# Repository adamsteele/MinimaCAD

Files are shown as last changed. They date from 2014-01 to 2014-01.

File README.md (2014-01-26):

Minima CAD
==========

Credit goes to Adrian over at http://yo4hhp.wordpress.com/ who did the original Eagle work and Ashhar Farhan over at http://www.phonestack.com/farhan/minima.html for the original Minima design.

There is a mailing list at http://www.freelists.org/archive/minima/recent for the Minima radio.

==========

What I've done is combine the two radio boards in to a single eagle brd/sch file and wrote up a BOM for DigiKey.
What I'd like to do is be able to run boards off at OSHPark, buy a bag of parts of DigiKey and have a radio.

What still needs done:

- [ ] Hole Drill Sizes. Adrian designed this for ease of home manufacture not for OSHPark so it will take some tweaks.
- [ ] Cleanup silkscreen. It's pretty clean already there's just a bit of overlap here and there.
- [ ] Cleanup part values for consistency
- [ ] Cleanup BOM. There are a few resistor/capacitor lines that could be combined.
- [ ] Verify BOM. I went through and generally picked the cheapest parts available. Many of these have fairly loose tolerances which might not work in a radio (I don't know).

==========

Quick Notes:
- These boards aren't ready yet for OSHPark so don't spend the money on it just yet.
- The BOM is reasonably complete but it is missing tuning inductors and a knob. Money could easily be saved by not buying SMA connectors and using a bit of coax. The LCD could also be bought elsewhere to save money.

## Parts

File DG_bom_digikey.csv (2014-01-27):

Total part count: |  | 33 |  |  |  | BOM Cost: | $30.93
QTY | Value | Device | Parts | Description | Digikey P/N | Price at QTY | Total $ | URL
1 |  | 78XXL | IC4 | VOLTAGE REGULATOR | MC7805CT-BPMS-ND | $0.48 | $0.48 | http://www.digikey.com/product-detail/en/MC7805CT-BP/MC7805CT-BPMS-ND/804682
1 |  | PINHD-1X4 | BAND | PIN HEADER | - | - | - | -
1 |  | SI57X | IC2 | Any Rate I2C Prorammable XO/VCXO SiliconLabs Si570 XO and Si571 VCXO | 336-2518-ND | $13.11 | $13.11 | http://www.digikey.com/product-detail/en/570CAC000141DG/336-2518-ND/3991067
4 | 0.1 | C-EU050-024X044 | C4, C6, C7, C8 | CAPACITOR, European symbol | 445-8421-ND | $0.20 | $0.80 | http://www.digikey.com/product-detail/en/FK18X7R1E104K/445-8421-ND/2815351
1 | 10k | R-EU_0204/5 | R7 | RESISTOR, European symbol | CF18JT10K0CT-ND | $0.09 | $0.09 | http://www.digikey.com/product-detail/en/CF18JT10K0/CF18JT10K0CT-ND/2022766
1 | 10k | TRIM_EU-CA6V | R1 | POTENTIOMETER | 3306F-103-ND | $0.41 | $0.41 | http://www.digikey.com/product-detail/en/3306F-1-103/3306F-103-ND/84666
1 | 10u | CPOL-EUE2.5-5 | C1 | POLARIZED CAPACITOR, European symbol | 493-12772-1-ND | $0.12 | $0.12 | http://www.digikey.com/product-detail/en/UVR1E100MDD6TP/493-12772-1-ND/4328365
1 | 12V | PINHD-1X2 | 12V | PIN HEADER | - | - | - | -
1 | 16MHz | CRYSTALHC49S | Q1 | CRYSTAL | CTX1085-ND | $0.36 | $0.36 | http://www.digikey.com/product-detail/en/ATS16B/CTX1085-ND/2640031
1 | 1k | R-EU_0204/5 | R4 | RESISTOR, European symbol | CF18JT1K00CT-ND | $0.07 | $0.07 | http://www.digikey.com/product-detail/en/CF18JT1K00/CF18JT1K00CT-ND/2022742
2 | 22p | C-EUC1206 | C2, C3 | CAPACITOR, European symbol | 1276-2820-1-ND | $0.10 | $0.20 | http://www.digikey.com/product-detail/en/CL31C220JCCNNNC/1276-2820-1-ND/3890906
1 | 33R | R-EU_0207/15 | R2 | RESISTOR, European symbol | CF14JT33R0CT-ND | $0.08 | $0.08 | http://www.digikey.com/product-detail/en/CF14JT33R0/CF14JT33R0CT-ND/1830315
2 | 4k7 | R-EU_0204/5 | R5, R6 | RESISTOR, European symbol | CF18JT4K70CT-ND | $0.09 | $0.18 | http://www.digikey.com/product-detail/en/CF18JT4K70/CF18JT4K70CT-ND/2022758
1 | 50u | CPOL-EUE2.5-5 | C5 | POLARIZED CAPACITOR, European symbol | 493-12597-1-ND | $0.15 | $0.15 | http://www.digikey.com/product-detail/en/UVK1V470MDD1TD/493-12597-1-ND/4328678
1 | 5V | PINHD-1X1 | 5V | PIN HEADER | - | - | - | -
1 | 7805 | LM1117TO252 | IC3 |  | 1016-1584-1-ND | $0.66 | $0.66 | http://www.digikey.com/product-detail/en/SP7805V2-L%2FTR/1016-1584-1-ND/2687706
1 | BFO | PINHD-1X1 | BFO | PIN HEADER | - | - | - | -
1 | CW | PINHD-1X1 | CW | PIN HEADER | - | - | - | -
1 | FN | PINHD-1X2 | FN | PIN HEADER | - | - | - | -
1 | KEY | PINHD-1X2 | KEY | PIN HEADER | - | - | - | -
1 | MEGA8-P | MEGA8-P | IC1 | MICROCONTROLLER | ATMEGA328P-PU-ND | $3.23 | $3.23 | http://www.digikey.com/product-detail/en/ATMEGA328P-PU/ATMEGA328P-PU-ND/1914589
1 | PTT | PINHD-1X2 | PTT | PIN HEADER | - | - | - | -
1 | RST | PINHD-1X2 | RST | PIN HEADER | - | - | - | -
1 | SERIAL | PINHD-1X2 | PC | PIN HEADER | - | - | - | -
1 | T/R | PINHD-1X1 | T/R | PIN HEADER | - | - | - | -
1 | TUNE | PINHD-1X3 | TUNE | PIN HEADER | - | - | - | -
1 | TUXGR_16X2_R2 | TUXGR_16X2_R2 | DIS1 | Tuxgraphics LCD display 16x2 characters reflective, without background light | 67-1781-ND | $8.38 | $8.38 | http://www.digikey.com/product-detail/en/LCM-S01602DTR%2FM/67-1781-ND/469805
1 | VFO | BU-SMA-H | X2 | FEMALE SMA CONNECTOR | CONSMA001-ND | $2.61 | $2.61 | http://www.digikey.com/product-detail/en/CONSMA001/CONSMA001-ND/1577202

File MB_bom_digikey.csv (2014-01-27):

Total part count: |  | 204 |  |  |  | BOM Cost: | $51.26
QTY | Value | Device | Parts | Description | Digikey P/N | Price at QTY | Total $ | URL
16 | 0.1 uF | C-EU050-024X044 | C9, C56, C58, C59, C60, C61, C62, C63,C64, C65, C66, C67, C70, C71, C72, C73 | CAPACITOR, European symbol | 445-8421-ND | $0.20 | $3.20 | http://www.digikey.com/product-detail/en/FK18X7R1E104K/445-8421-ND/2815351
3 | 22 pF | C-TRIMMTZ03 | C57, C68, C69 | Trimm capacitor | SG3009-ND | $1.84 | $5.52 | http://www.digikey.com/product-detail/en/GYC65000/SG3009-ND/65256
1 | 1 uF | CPOL-EUE5-4 | C50 | POLARIZED CAPACITOR, European symbol | 493-12600-1-ND | $0.15 | $0.15 | http://www.digikey.com/product-detail/en/UVK2A010MDD1TD/493-12600-1-ND/4328681
8 | 20 MHz | CRYSTALHC49S | Q1, Q2, Q3, Q4, Q5, Q6, Q7, Q9 | CRYSTAL | CTX1106-ND | $0.36 | $2.88 | http://www.digikey.com/product-detail/en/ATS20A/CTX1106-ND/2640038
3 | 1N4007 |  | D1, D2, D3 | DIODE | 1N4007-TPMSCT-ND | $0.11 | $0.33 | http://www.digikey.com/product-detail/en/1N4007-TP/1N4007-TPMSCT-ND/773694
4 | 1N4148 | DIODE-D-5 | D4, D5, D6, D7 | DIODE | 1N4148TACT-ND | $0.10 | $0.40 | http://www.digikey.com/product-detail/en/1N4148TA/1N4148TACT-ND/1532747
1 | - | PINHD-1X1 | JP27 | PIN HEADER | - | - | -
15 | - | PINHD-1X2 | JP5, JP11, JP12, JP15, JP16, JP17, JP18, JP19, JP20, JP21, JP22, JP23, JP24, JP25, JP26 | PIN HEADER | - | - | -
3 | - | PINHD-2X3 | JP1, JP3, JP4 | PIN HEADER | - | - | -
1 | 10k | R-EU_0204/5 | R14 | RESISTOR, European symbol | CF18JT10K0CT-ND | $0.09 | $0.09 | http://www.digikey.com/product-detail/en/CF18JT10K0/CF18JT10K0CT-ND/2022766
18 | 0.1 | C-EU050-024X044 | C6, C7, C8, C10, C11, C12, C13, C14, C15, C16, C19, C22, C23, C24, C39, C42, C44, C45 | CAPACITOR, European symbol | 445-8421-ND | $0.20 | $3.60 | http://www.digikey.com/product-detail/en/FK18X7R1E104K/445-8421-ND/2815351
6 | 10 | R-EU_0204/5 | R2, R7, R17, R24, R51, R55 | RESISTOR, European symbol | CF18JT10R0CT-ND | $0.07 | $0.39 | http://www.digikey.com/product-detail/en/CF18JT10R0/CF18JT10R0CT-ND/2022697
2 | 100 | R-EU_0204/5 | R18, R30 | RESISTOR, European symbol | CF18JT100RCT-ND | $0.09 | $0.18 | http://www.digikey.com/product-detail/en/CF18JT100R/CF18JT100RCT-ND/2022718
2 | 100k | R-EU_0204/5 | R35, R41 | RESISTOR, European symbol | CF18JT100KCT-ND | $0.09 | $0.18 | http://www.digikey.com/product-detail/en/CF18JT100K/CF18JT100KCT-ND/2022790
2 | 100p | C-EU050-024X044 | C17, C18 | CAPACITOR, European symbol | 478-4214-1-ND | $0.25 | $0.50 | http://www.digikey.com/product-detail/en/5MQ101KOAAM/478-4214-1-ND/1220585
5 | 100p | C-EUC1206 | C1, C2, C3, C4, C5 | CAPACITOR, European symbol | 1276-2799-1-ND | $0.12 | $0.60 | http://www.digikey.com/product-detail/en/CL31C101JCCNFNC/1276-2799-1-ND/3890885
8 | 10k | R-EU_0204/5 | R8, R22, R23, R33, R39, R42, R46, R56 | RESISTOR, European symbol | CF18JT10K0CT-ND | $0.09 | $0.72 | http://www.digikey.com/product-detail/en/CF18JT10K0/CF18JT10K0CT-ND/2022766
1 | 10k | TRIM_EU-CA6V | R26 | POTENTIOMETER | 3306F-103-ND | $0.41 | $0.41 | http://www.digikey.com/product-detail/en/3306F-1-103/3306F-103-ND/84666
3 | 10n | C-EU050-024X044 | C47, C48, C49 | CAPACITOR, European symbol | 445-8421-ND | $0.20 | $0.60 | http://www.digikey.com/product-detail/en/FK18X7R1E104K/445-8421-ND/2815351
1 | 10u | CPOL-EUE2.5-5 | C28 | POLARIZED CAPACITOR, European symbol | 493-12772-1-ND | $0.12 | $0.12 | http://www.digikey.com/product-detail/en/UVR1E100MDD6TP/493-12772-1-ND/4328365
1 | 10 | R-EU_0204/5 | R48 | RESISTOR, European symbol | CF18JT10R0CT-ND | $0.07 | $0.07 | http://www.digikey.com/product-detail/en/CF18JT10R0/CF18JT10R0CT-ND/2022697
11 | 1k | R-EU_0204/5 | R9, R10, R13, R20, R21, R36, R37, R40, R47, R60, R61 | RESISTOR, European symbol | CF18JT1K00CT-ND | $0.07 | $0.72 | http://www.digikey.com/product-detail/en/CF18JT1K00/CF18JT1K00CT-ND/2022742
3 | 1u | CPOL-EUE2.5-5 | C35, C38, C41 | POLARIZED CAPACITOR, European symbol | 493-12600-1-ND | $0.15 | $0.45 | http://www.digikey.com/product-detail/en/UVK2A010MDD1TD/493-12600-1-ND/4328681
3 | 22 | R-EU_0204/5 | R27, R28, R34 | RESISTOR, European symbol | CF18JT22R0CT-ND | $0.09 | $0.27 | http://www.digikey.com/product-detail/en/CF18JT22R0/CF18JT22R0CT-ND/2022702
7 | 220 | R-EU_0204/5 | R1, R4, R5, R12, R43, R44, R53 | RESISTOR, European symbol | CF18JT220RCT-ND | $0.09 | $0.63 | http://www.digikey.com/product-detail/en/CF18JT220R/CF18JT220RCT-ND/2022726
2 | 22 pF | C-TRIMMTZ03 | C26, C27 | Trimm capacitor | SG3009-ND | $1.84 | $3.68 | http://www.digikey.com/product-detail/en/GYC65000/SG3009-ND/65256
1 | 2K2 | R-EU_0204/5 | R50 | RESISTOR, European symbol | CF18JT2K20CT-ND | $0.09 | $0.09 | http://www.digikey.com/product-detail/en/CF18JT2K20/CF18JT2K20CT-ND/2022750
19 | 2N3904 | 2N3904 | Q8, Q10, Q11, Q12, Q13, Q14, Q15, Q16, Q20, Q22, Q23, Q24, Q25, Q26, Q27, Q28, Q29, Q30, Q39 | NPN Transistor | 2N3904-APCT-ND | $0.17 | $3.23 | http://www.digikey.com/product-detail/en/2N3904-AP/2N3904-APCT-ND/950591
1 | 2N3906 | 2N3906 | Q21 | PNP Transistor | 2N3906-APCT-ND | $0.19 | $0.19 | http://www.digikey.com/product-detail/en/2N3906-AP/2N3906-APCT-ND/950592
5 | 2k2 | R-EU_0204/5 | R3, R6, R11, R29, R45 | RESISTOR, European symbol | CF18JT2K20CT-ND | $0.09 | $0.45 | http://www.digikey.com/product-detail/en/CF18JT2K20/CF18JT2K20CT-ND/2022750
1 | 3u | L-US0207/2V | L1 | INDUCTOR, American symbol | 495-5600-1-ND | $1.33 | $1.33 | http://www.digikey.com/product-detail/en/B82131A5202M/495-5600-1-ND/4245925
2 | 470 | R-EU_0204/5 | R15, R31 | RESISTOR, European symbol | CF18JT470RCT-ND | $0.09 | $0.18 | http://www.digikey.com/product-detail/en/CF18JT470R/CF18JT470RCT-ND/2022734
1 | 470u | CPOL-EUE2.5-5 | C30 | POLARIZED CAPACITOR, European symbol | 493-12892-1-ND | $0.18 | $0.18 | http://www.digikey.com/product-detail/en/UVY1A471MED1TD/493-12892-1-ND/4328509
2 | 47k | R-EU_0204/5 | R32, R59 | RESISTOR, European symbol | CF18JT47K0CT-ND | $0.09 | $0.18 | http://www.digikey.com/product-detail/en/CF18JT47K0/CF18JT47K0CT-ND/2022782
7 | 4k7 | R-EU_0204/5 | R16, R25, R38, R49, R52, R54, R64 | RESISTOR, European symbol | CF18JT4K70CT-ND | $0.09 | $0.63 | http://www.digikey.com/product-detail/en/CF18JT4K70/CF18JT4K70CT-ND/2022758
12 | 50u | CPOL-EUE2.5-5 | C20, C21, C25, C29, C31, C32, C33, C36, C37, C40, C43, C46 | POLARIZED CAPACITOR, European symbol | 445-8425-ND | $0.22 | $2.66 | http://www.digikey.com/product-detail/en/FK18X7R1E474K/445-8425-ND/2815355
1 | 51 | R-EU_0204/5 | R19 | RESISTOR, European symbol | CF18JT51R0CT-ND | $0.09 | $0.09 | http://www.digikey.com/product-detail/en/CF18JT51R0/CF18JT51R0CT-ND/2022711
2 | 6k8 | R-EU_0204/5 | R57, R58 | RESISTOR, European symbol | CF18JT6K80CT-ND | $0.09 | $0.18 | http://www.digikey.com/product-detail/en/CF18JT6K80/CF18JT6K80CT-ND/2022762
1 | 78L05 | 78LXX | IC1 | VOLTAGE REGULATOR | 497-2952-ND | $0.39 | $0.39 | http://www.digikey.com/product-detail/en/L78L05ACZ/497-2952-ND/634716
1 | 20 MHz (BFO) | CRYSTALHC49S | Q17 | CRYSTAL | CTX1106-ND | $0.36 | $0.36 | http://www.digikey.com/product-detail/en/ATS20A/CTX1106-ND/2640038
1 | BFO | PINHD-1X1 | JP9 | PIN HEADER | - | - | -
1 | CW | PINHD-1X1 | JP10 | PIN HEADER | - | - | -
1 | 12VDC | G5V-2 | K2 | OMRON PCB Relay | Z768-ND | $2.97 | $2.97 | http://www.digikey.com/product-detail/en/G5V-2-DC12/Z768-ND/87821
3 | G5V1 | G5V1 | K1, K3, K4 | RELAY | Z774-ND | $2.05 | $6.15 | http://www.digikey.com/product-detail/en/G5V-1-DC12/Z774-ND/87833
2 | J310 | J310 | Q18, Q19 | N-Channel RF Amplifier J309, J310 | J310GOS-ND | $0.55 | $1.10 | http://www.digikey.com/product-detail/en/J310G/J310GOS-ND/918462
1 | MIC | PINHD-1X2 | JP6 | PIN HEADER | - | - | -
4 | PAD-RND3.0 | PAD-RND3.0 | H1, H2, H3, H4 | MOUNTING PAD, round | - | - | -
1 | PA | BU-SMA-V | X3 | FEMALE SMA CONNECTOR | CONSMA001-ND | $2.61 | $2.61 | http://www.digikey.com/product-detail/en/CONSMA001/CONSMA001-ND/1577202
1 | R/T | PINHD-1X1 | JP8 | PIN HEADER | - | - | -
1 | RFC | PINHD-1X2 | JP2 | PIN HEADER | - | - | -
1 | VFO | BU-SMA-V | X1 | FEMALE SMA CONNECTOR | CONSMA001-ND | $2.61 | $2.61 | http://www.digikey.com/product-detail/en/CONSMA001/CONSMA001-ND/1577202
1 | VOL | PINHD-1X3 | JP7 | PIN HEADER | - | - | -

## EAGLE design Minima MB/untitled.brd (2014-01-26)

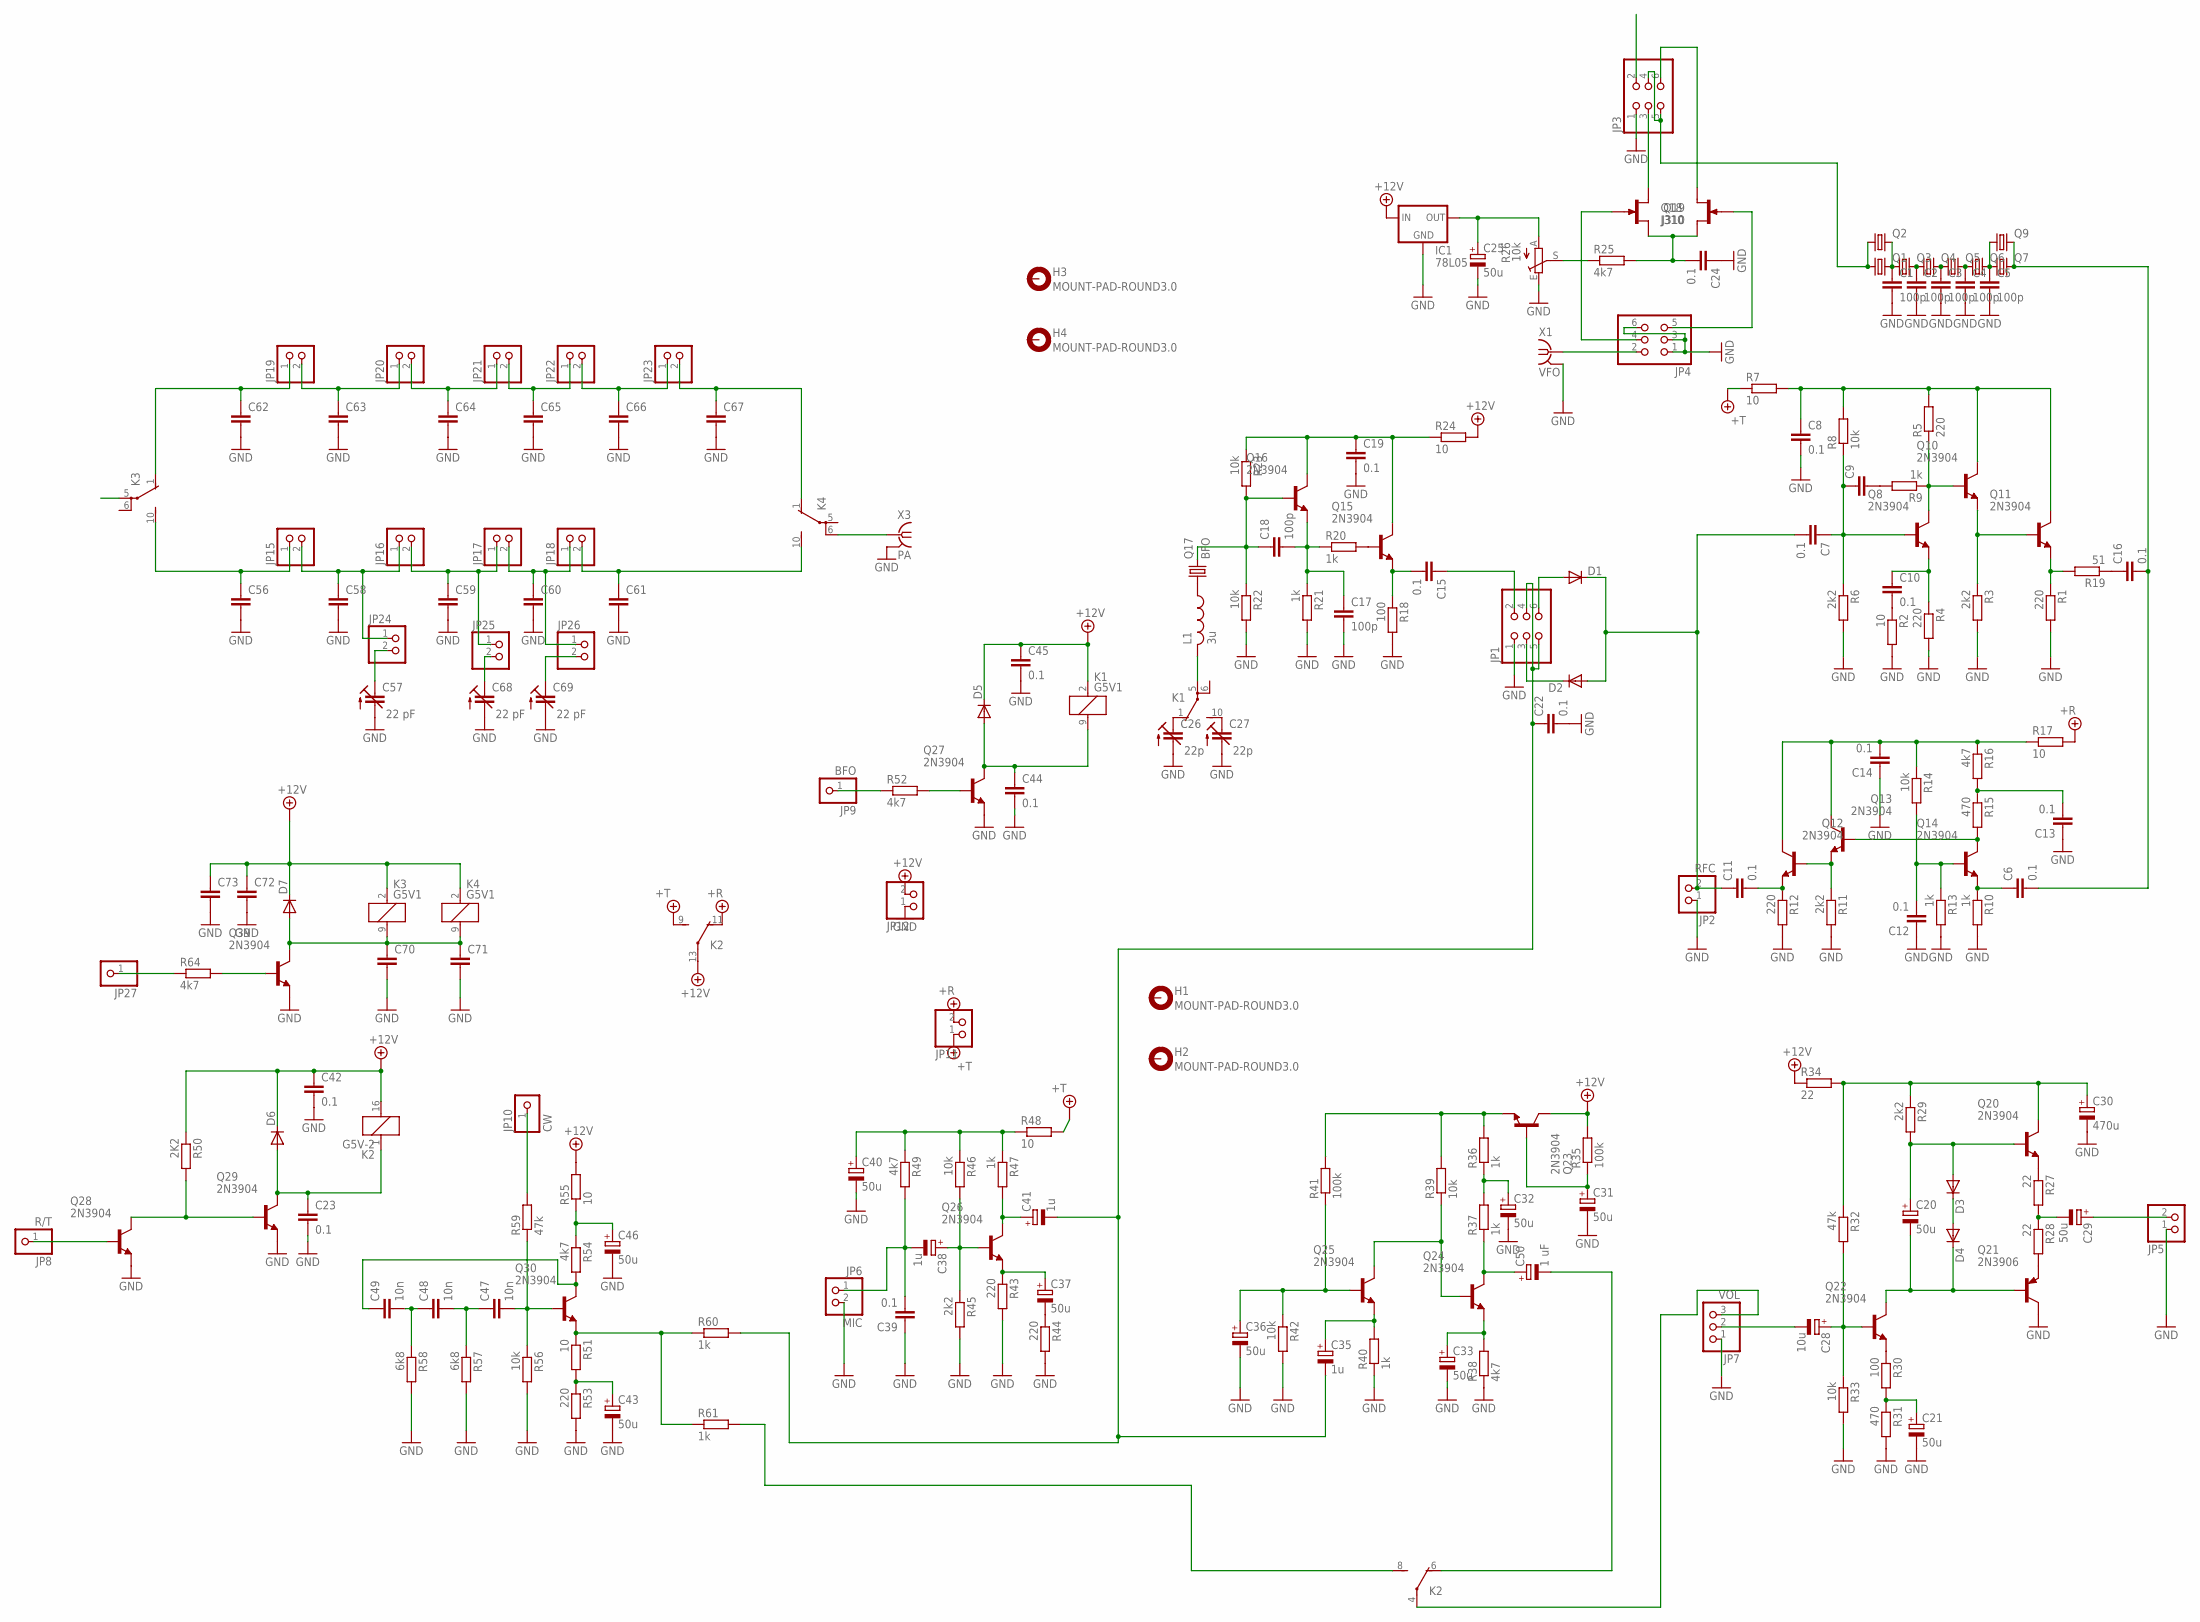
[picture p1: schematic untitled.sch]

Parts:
C1, C2, C3, C4, C5: 100p; C1206
C6, C7, C8, C10, C11, C12, C13, C14, C15, C16, C19, C22, C23, C24, C39, C42, C44, C45: 0.1; C050-024X044
C9, C56, C58, C59, C60, C61, C62, C63, C64, C65, C66, C67, C70, C71, C72, C73: C-EU050-024X044; C050-024X044
C17, C18: 100p; C050-024X044
C20, C21, C25, C29, C31, C32, C33, C36, C37, C40, C43, C46: 50u; E2,5-5
C26, C27: 22p; CTRIMTZ03
C28: 10u; E2,5-5
C30: 470u; E2,5-5
C35, C38, C41: 1u; E2,5-5
C47, C48, C49: 10n; C050-024X044
C50: 1 uF; E5-4
C57, C68, C69: 22 pF; CTRIMTZ03
D1, D2, D3, D4, D5, D6, D7: DIODE-D-5; D-5
H1, H2, H3, H4: MOUNT-PAD-ROUND3.0; 3,0-PAD
IC1: 78L05; 78LXX
JP1, JP3, JP4: PINHD-2X3; 2X03
JP2: RFC; 1X02
JP5, JP11, JP12, JP15, JP16, JP17, JP18, JP19, JP20, JP21, JP22, JP23, JP24, JP25, JP26: PINHD-1X2; 1X02
JP6: MIC; 1X02
JP7: VOL; 1X03
JP8: R/T; 1X01
JP9: BFO; 1X01
JP10: CW; 1X01
JP27: PINHD-1X1; 1X01
K1, K3, K4: G5V1
K2: G5V-2
L1: 3u; 0207/2V
Q1, Q2, Q3, Q4, Q5, Q6, Q7, Q9: CRYSTALHC49S; HC49/S
Q8, Q10, Q11, Q12, Q13, Q14, Q15, Q16, Q20, Q22, Q23, Q24, Q25, Q26, Q27, Q28, Q29, Q30, Q39: 2N3904; TO92
Q17: BFO; HC49/S
Q18, Q19: J310; TO92R
Q21: 2N3906; TO92
R1, R4, R5, R12, R43, R44, R53: 220; 0204/5
R2, R7, R17, R24, R48, R51, R55: 10; 0204/5
R3, R6, R11, R29, R45: 2k2; 0204/5
R8, R14, R22, R23, R33, R39, R42, R46, R56: 10k; 0204/5
R9, R10, R13, R20, R21, R36, R37, R40, R47, R60, R61: 1k; 0204/5
R15, R31: 470; 0204/5
R16, R25, R38, R49, R52, R54, R64: 4k7; 0204/5
R18, R30: 100; 0204/5
R19: 51; 0204/5
R26: 10k; CA6V
R27, R28, R34: 22; 0204/5
R32, R59: 47k; 0204/5
R35, R41: 100k; 0204/5
R50: 2K2; 0204/5
R57, R58: 6k8; 0204/5
X1: VFO; BU-SMA-V
X3: PA; BU-SMA-V

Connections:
+5V/1: JP11.2, K2.11 (O), R17.2
+5V/2: JP11.1, K2.9 (S), R7.1, R48.2
+12V: C42.1, C45.1, C72.1, C73.1, D5.C, D6.C, D7.C, IC1.IN, JP12.2, K1.2 (1), K2.13, K2.16 (2), K3.2 (1), K4.2 (1), Q23.1 (C), R24.2, R34.1, R35.2, R50.1, R55.2
GND: C1.2, C2.2, C3.2, C4.2, C5.2, C8.2, C12.1, C13.1, C14.1, C17.2, C19.2, C21.-, C22.2, C23.2, C24.1, C25.-, C26.2 (A), C27.2 (A), C30.-, C31.-, C32.-, C33.-, C36.-, C39.1, C40.-, C42.2, C43.-, C44.2, C45.2, C46.-, C56.2, C57.2 (A), C58.2, C59.2, C60.2, C61.2, C62.2, C63.2, C64.2, C65.2, C66.2, C67.2, C68.2 (A), C69.2 (A), C70.2, C71.2, C72.2, C73.2, IC1.GND, JP1.1, JP2.1, JP3.1, JP4.1, JP4.3, JP4.6, JP5.1, JP6.2, JP7.1, JP12.1, Q21.1 (C), Q27.3 (E), Q28.3 (E), Q29.3 (E), Q39.3 (E), R1.2, R2.2, R3.2, R4.2, R6.2, R10.2, R11.2, R12.2, R13.2, R18.2, R21.2, R22.2, R26.E, R31.2, R33.2, R38.1, R40.1, R42.2, R43.2, R44.2, R45.2, R53.2, R56.2, R57.2, R58.2, X1.2 (GND), X1.3 (GND), X1.4 (GND), X1.5 (GND), X3.2 (GND), X3.3 (GND), X3.4 (GND), X3.5 (GND)
unnamed: C1.1, Q1.2, Q2.2, Q3.1
unnamed: C2.1, Q3.2, Q4.1
unnamed: C3.1, Q4.2, Q5.1
unnamed: C4.1, Q5.2, Q6.1
unnamed: C5.1, Q6.2, Q7.1, Q9.1
unnamed: C6.2, C16.2, Q7.2, Q9.2
unnamed: C26.1 (E), K1.1 (O)
unnamed: C10.1, Q8.3 (E), R4.1
unnamed: C10.2, R2.1
unnamed: C7.1, C9.1, Q8.2 (B), R6.1, R8.1
unnamed: Q8.1 (C), Q10.2 (B), R5.1, R9.1
unnamed: Q10.3 (E), Q11.2 (B), R3.1
unnamed: Q11.3 (E), R1.1, R19.2
unnamed: C8.1, Q10.1 (C), Q11.1 (C), R5.2, R7.2, R8.2
unnamed: C16.1, R19.1
unnamed: C9.2, R9.2
unnamed: Q12.2 (B), Q13.3 (E), R11.1
unnamed: C11.2, Q12.3 (E), R12.1
unnamed: C14.2, Q12.1 (C), Q13.1 (C), R14.1, R16.1, R17.1
unnamed: C27.1 (E), K1.10 (S)
unnamed: C12.2, Q14.2 (B), R13.1, R14.2
unnamed: C6.1, Q14.3 (E), R10.1
unnamed: Q13.2 (B), Q14.1 (C), R15.2
unnamed: C13.2, R15.1, R16.2
unnamed: C15.2, Q15.3 (E), R18.1
unnamed: Q15.2 (B), R20.2
unnamed: C17.1, C18.2, Q16.3 (E), R20.1, R21.1
unnamed: C19.1, Q15.1 (C), Q16.1 (C), R23.1, R24.1
unnamed: C15.1, JP1.2
unnamed: C18.1, Q16.2 (B), Q17.2, R22.1, R23.2
unnamed: L1.1, Q17.1
unnamed: K1.5, L1.2
unnamed: R25.1, R26.S
unnamed: Q20.3 (E), R27.1
unnamed: Q27.2 (B), R52.2
unnamed: D1.A, JP1.6
unnamed: D2.C, JP1.3
unnamed: C7.2, C11.1, D1.C, D2.A, JP2.2
unnamed: JP3.4, JP3.5, Q1.1, Q2.1
unnamed: JP3.3, Q18.D
unnamed: JP3.6, Q19.D
unnamed: C24.2, Q18.S, Q19.S, R25.2
unnamed: JP4.5, Q19.G
unnamed: JP4.4, Q18.G
unnamed: C29.-, R27.2, R28.1
unnamed: JP4.2, X1.1
unnamed: Q21.3 (E), R28.2
unnamed: C25.+, IC1.OUT, R26.A
unnamed: D3.C, D4.A
unnamed: C20.-, D4.C, Q21.2 (B), Q22.1 (C)
unnamed: C20.+, D3.A, Q20.2 (B), R29.2
unnamed: C30.+, Q20.1 (C), R29.1, R32.1, R34.2
unnamed: Q22.3 (E), R30.1
unnamed: C21.+, R30.2, R31.1
unnamed: C28.+, Q22.2 (B), R32.2, R33.1
unnamed: C29.+, JP5.2
unnamed: C28.-, JP7.2
unnamed: C31.+, Q23.2 (B), R35.1
unnamed: Q23.3 (E), R36.2, R39.2, R41.2
unnamed: C32.+, R36.1, R37.2
unnamed: C50.+, Q24.1 (C), R37.1
unnamed: C33.+, Q24.3 (E), R38.2
unnamed: Q24.2 (B), Q25.1 (C), R39.1
unnamed: JP9.1, R52.1
unnamed: C35.+, Q25.3 (E), R40.2
unnamed: C36.+, Q25.2 (B), R41.1, R42.1
unnamed: C37.+, Q26.3 (E), R43.1
unnamed: C37.-, R44.1
unnamed: C38.+, Q26.2 (B), R45.1, R46.2
unnamed: C41.+, Q26.1 (C), R47.2
unnamed: C40.+, R46.1, R47.1, R48.1, R49.1
unnamed: C38.-, C39.2, JP6.1, R49.2
unnamed: JP7.3, K2.4
unnamed: C22.1, C35.-, C41.-, JP1.4, JP1.5, R60.2
unnamed: C50.-, K2.6 (O)
unnamed: JP8.1, Q28.2 (B)
unnamed: C23.1, D6.A, K2.1, Q29.1 (C)
unnamed: Q28.1 (C), Q29.2 (B), R50.2
unnamed: C44.1, D5.A, K1.9 (2), Q27.1 (C)
unnamed: Q30.3 (E), R51.1, R60.1, R61.1
unnamed: C43.+, R51.2, R53.1
unnamed: C49.1, Q30.1 (C), R54.2
unnamed: C46.+, R54.1, R55.1
unnamed: C47.2, Q30.2 (B), R56.1, R59.1
unnamed: C47.1, C48.2, R57.1
unnamed: C48.1, C49.2, R58.1
unnamed: JP10.1, R59.2
unnamed: K2.8 (S), R61.2
unnamed: C56.1, JP15.1, K3.10 (S)
unnamed: C58.1, JP15.2, JP16.1, JP24.1
unnamed: C59.1, JP16.2, JP17.1, JP25.1
unnamed: C60.1, JP17.2, JP18.1, JP26.1
unnamed: C61.1, JP18.2, K4.10 (S)
unnamed: C62.1, JP19.1, K3.1 (O)
unnamed: C63.1, JP19.2, JP20.1
unnamed: C64.1, JP20.2, JP21.1
unnamed: C65.1, JP21.2, JP22.1
unnamed: C66.1, JP22.2, JP23.1
unnamed: C67.1, JP23.2, K4.1 (O)
unnamed: K4.6, X3.1
unnamed: JP3.2, K3.5
unnamed: C57.1 (E), JP24.2
unnamed: C68.1 (E), JP25.2
unnamed: C69.1 (E), JP26.2
unnamed: Q39.2 (B), R64.2
unnamed: JP27.1, R64.1
unnamed: C70.1, C71.1, D7.A, K3.9 (2), K4.9 (2), Q39.1 (C)

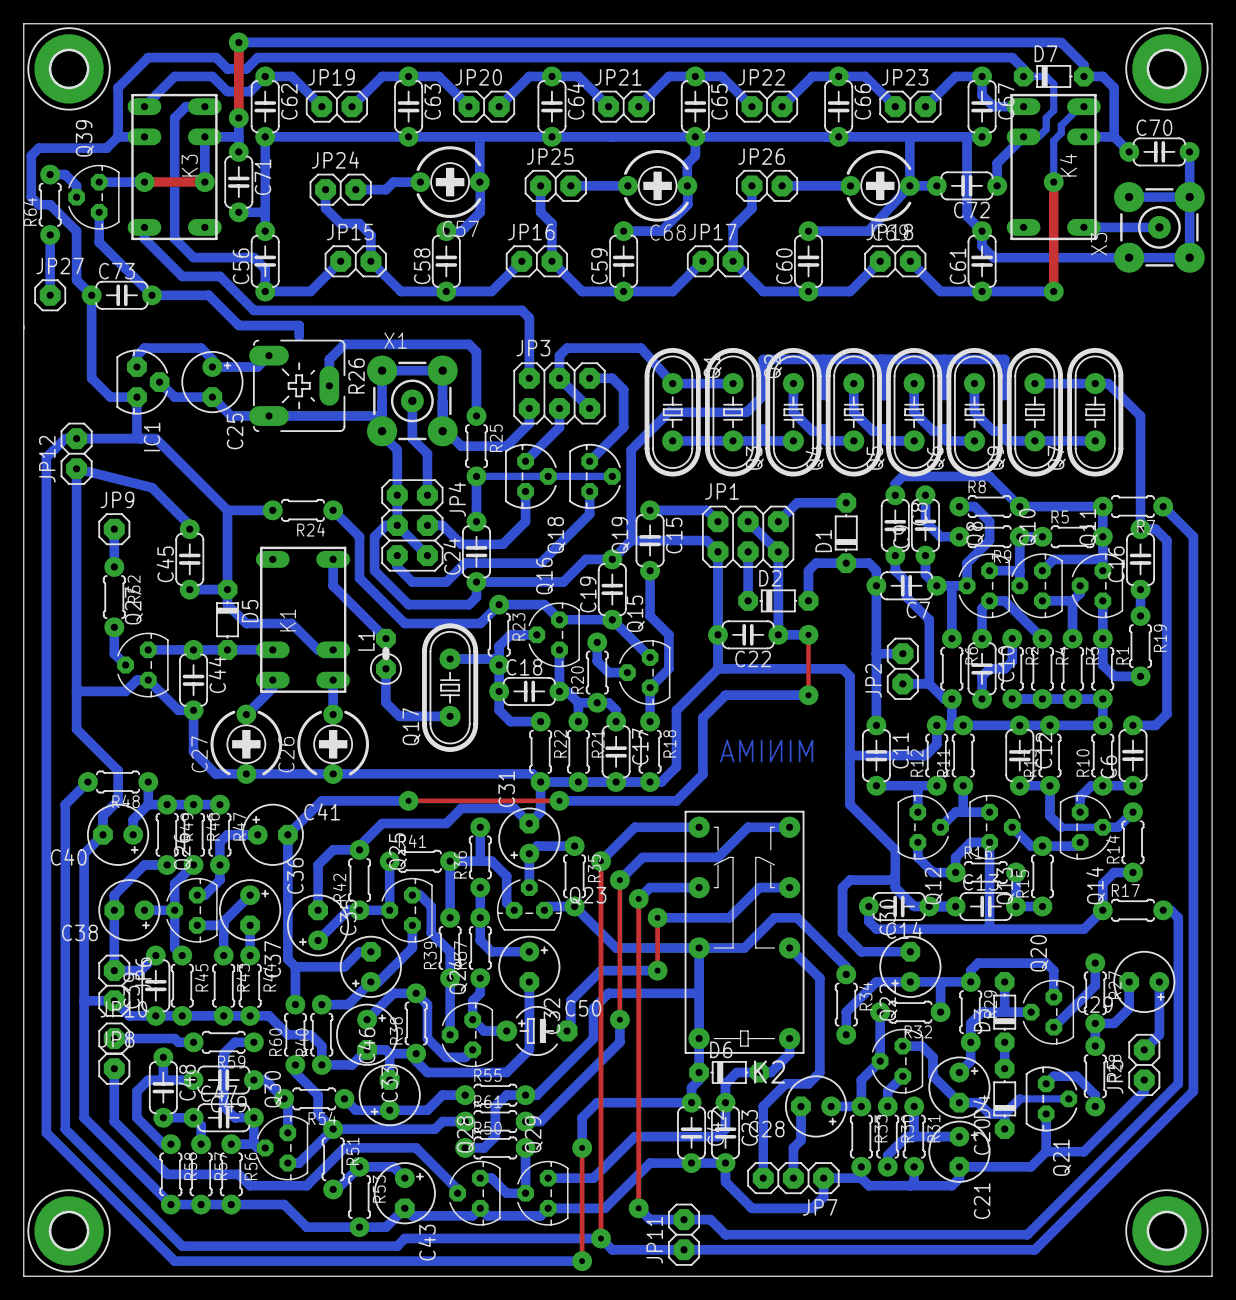
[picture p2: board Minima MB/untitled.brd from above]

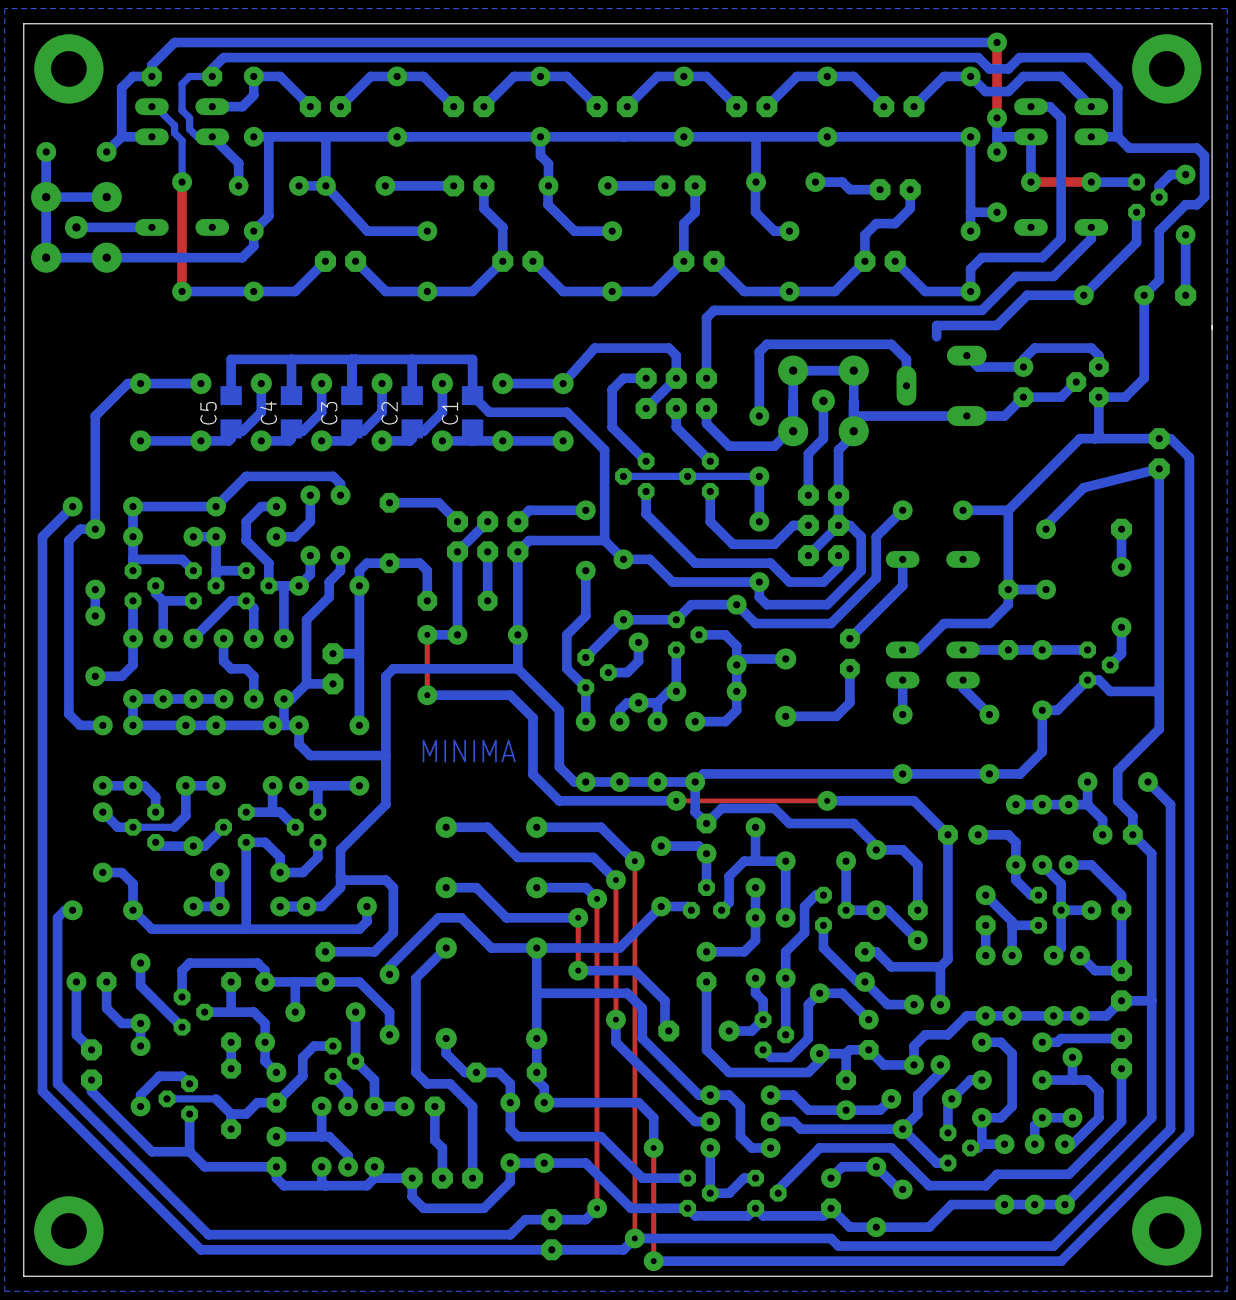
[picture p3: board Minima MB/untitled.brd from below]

Board: 2 copper layers, 100.0 x 105.4 mm, 204 parts (5 on the bottom side), 111 nets.

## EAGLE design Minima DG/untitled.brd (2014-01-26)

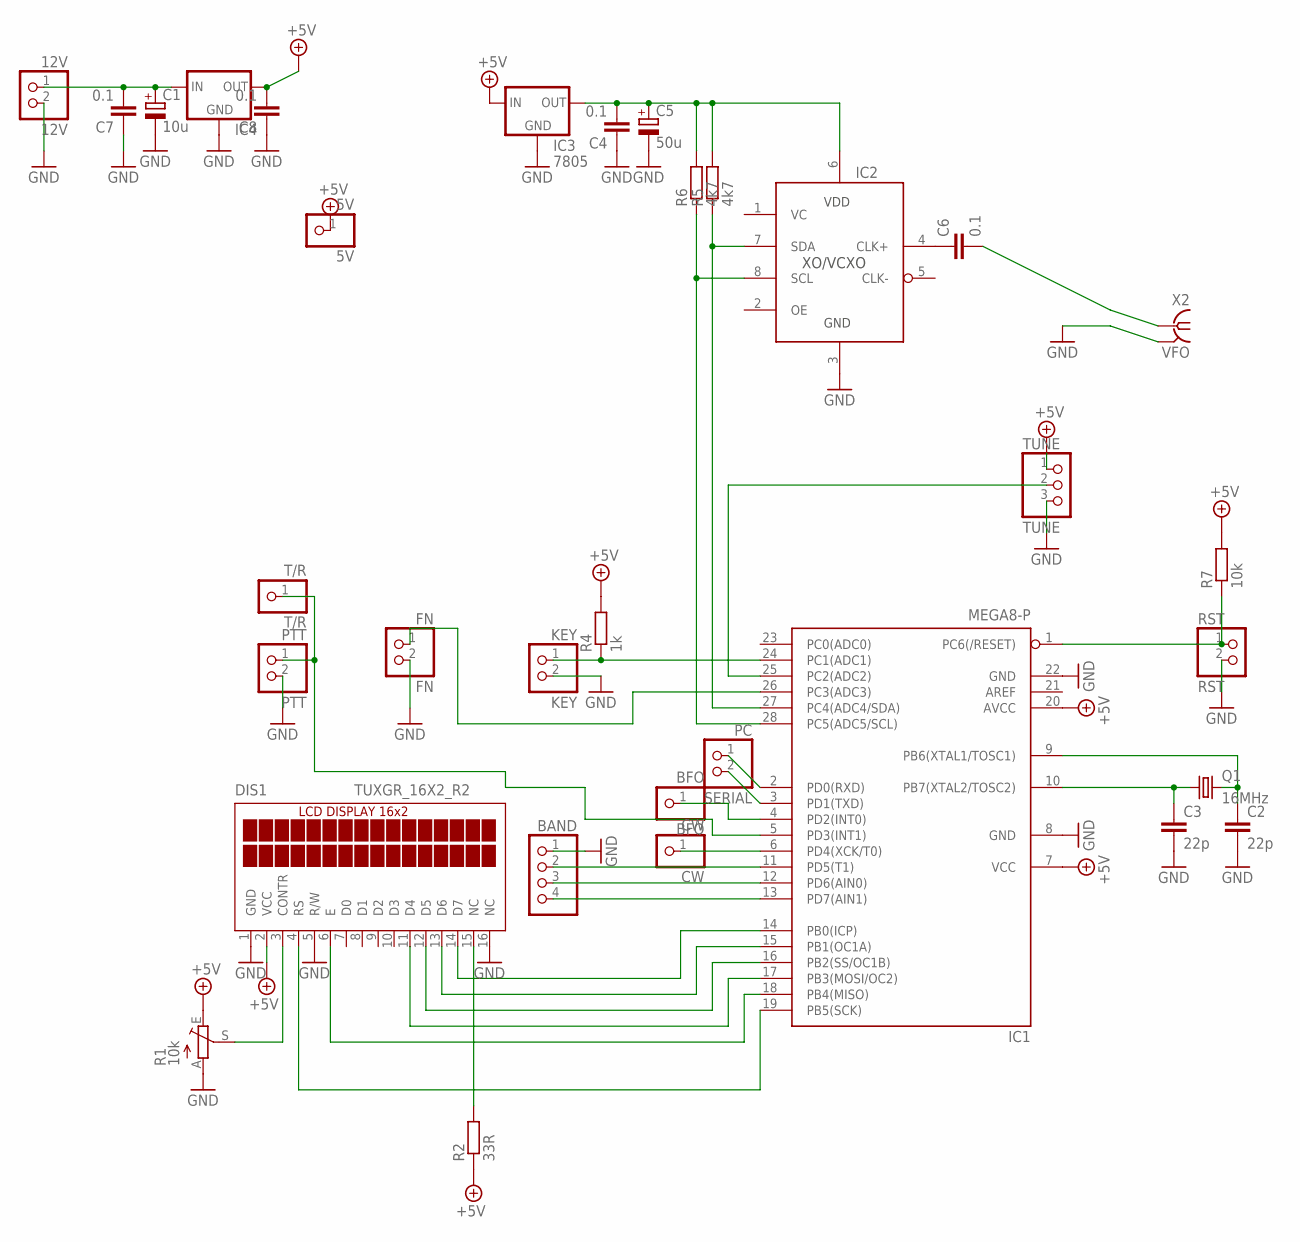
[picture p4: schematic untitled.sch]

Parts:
5V: 5V; 1X01
12V: 12V; 1X02
BAND: PINHD-1X4; 1X04
BFO: BFO; 1X01
C1: 10u; E2,5-5
C2, C3: 22p; C1206
C4, C6, C7, C8: 0.1; C050-024X044
C5: 50u; E2,5-5
CW: CW; 1X01
DIS1: TUXGR_16X2_R2
FN: FN; 1X02
IC1: MEGA8-P; DIL28-3
IC2: SI57X
IC3: 7805; TO252
IC4: 78XXL
KEY: KEY; 1X02
PC: SERIAL; 1X02
PTT: PTT; 1X02
Q1: 16MHz; HC49/S
R1: 10k; CA6V
R2: 33R; 0207/15
R4: 1k; 0204/5
R5, R6: 4k7; 0204/5
R7: 10k; 0204/5
RST: RST; 1X02
T/R: T/R; 1X01
TUNE: TUNE; 1X03
X2: VFO; BU-SMA-H

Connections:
+5V: 5V.1, C8.2, DIS1.2 (VCC), IC1.7 (VCC), IC1.20 (AVCC), IC3.2 (IN), IC4.OUT, R1.E, R2.1, R4.2, R7.2, TUNE.1
GND: 12V.2, BAND.1, C1.-, C2.2, C3.2, C4.1, C5.-, C7.1, C8.1, DIS1.1 (GND), DIS1.5 (R/W), DIS1.16 (NC), FN.2, IC1.8 (GND), IC1.22 (GND), IC2.3 (GND), IC3.1 (GND), IC4.GND, KEY.2, PTT.2, R1.A, RST.2, TUNE.3, X2.2 (GND), X2.3 (GND), X2.4 (GND), X2.5 (GND)
unnamed: DIS1.4 (RS), IC1.19 (PB5(SCK))
unnamed: DIS1.14 (D7), IC1.14 (PB0(ICP))
unnamed: DIS1.13 (D6), IC1.15 (PB1(OC1A))
unnamed: DIS1.12 (D5), IC1.16 (PB2(SS/OC1B))
unnamed: DIS1.11 (D4), IC1.17 (PB3(MOSI/OC2))
unnamed: DIS1.6 (E), IC1.18 (PB4(MISO))
unnamed: DIS1.3 (CONTR), R1.S
unnamed: DIS1.15 (NC), R2.2
unnamed: C2.1, IC1.9 (PB6(XTAL1/TOSC1)), Q1.2
unnamed: C3.1, IC1.10 (PB7(XTAL2/TOSC2)), Q1.1
unnamed: IC1.24 (PC1(ADC1)), KEY.1, R4.1
unnamed: BAND.2, IC1.11 (PD5(T1))
unnamed: BAND.3, IC1.12 (PD6(AIN0))
unnamed: BAND.4, IC1.13 (PD7(AIN1))
unnamed: FN.1, IC1.26 (PC3(ADC3))
unnamed: CW.1, IC1.6 (PD4(XCK/T0))
unnamed: IC1.5 (PD3(INT1)), PTT.1, T/R.1
unnamed: BFO.1, IC1.4 (PD2(INT0))
unnamed: IC1.27 (PC4(ADC4/SDA)), IC2.7 (SDA), R5.1
unnamed: IC1.28 (PC5(ADC5/SCL)), IC2.8 (SCL), R6.1
unnamed: C4.2, C5.+, IC2.6 (VDD), IC3.3 (OUT), R5.2, R6.2
unnamed: C6.1, IC2.4 (CLK+)
unnamed: C6.2, X2.1
unnamed: IC1.25 (PC2(ADC2)), TUNE.2
unnamed: IC1.1 (PC6(/RESET)), R7.1, RST.1
unnamed: 12V.1, C1.+, C7.2, IC4.IN
unnamed: IC1.2 (PD0(RXD)), PC.1
unnamed: IC1.3 (PD1(TXD)), PC.2

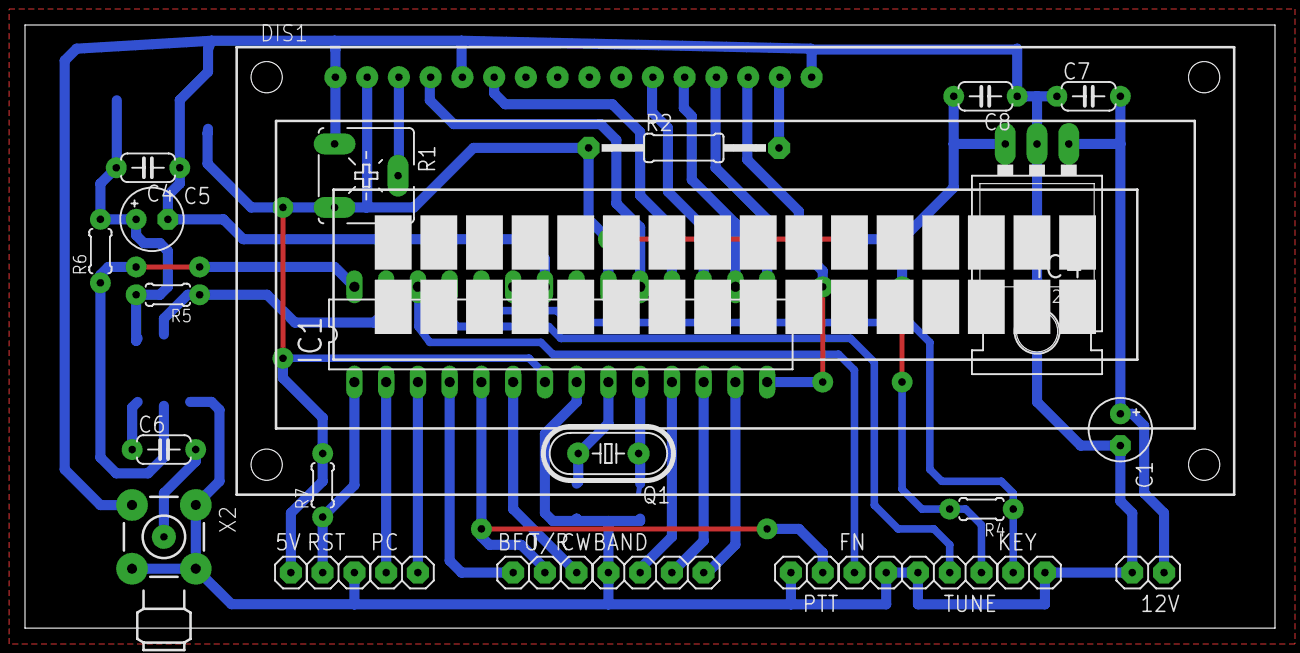
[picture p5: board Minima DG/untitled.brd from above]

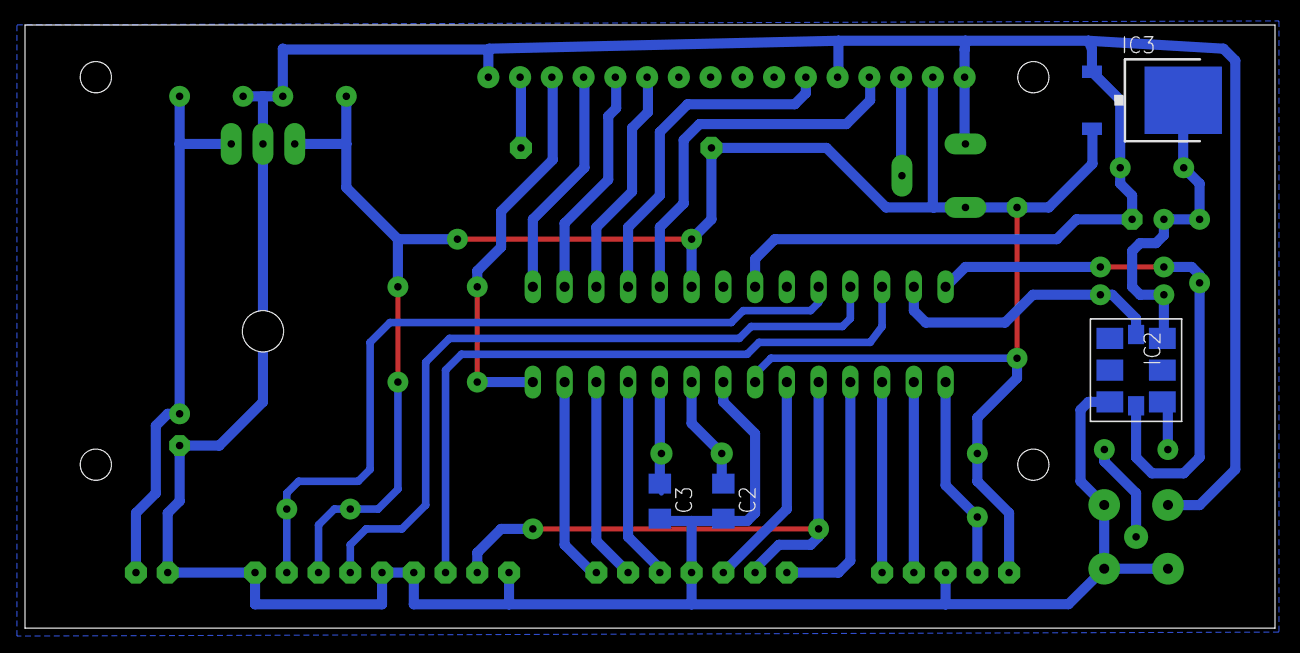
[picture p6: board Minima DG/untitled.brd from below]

Board: 2 copper layers, 100.0 x 48.2 mm, 33 parts (4 on the bottom side), 30 nets.

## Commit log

2014-01-25 Initial commit. Mostly merged the MB together, just need to delete the extra components used to line things up.
    [untitled B.brd, untitled B.sch, untitled.brd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]
2014-01-25 Deleted vestigle components, next I will shuffle the top half of the board back in to place.
    [untitled.brd]
2014-01-25 Halves joined, airwires connected, board dimension fixed and GND fill poly redone and added a TOP layer GND fill.
    Added BOMs as well.
    [untitled.brd]
2014-01-26 Added BOM files, remove unneeded files.
    [DG_bom_digikey.xlsx, MB_bom_digikey.xlsx, untitled B.brd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]
2014-01-27 Saved a copy of the BOMs as CSV
    [DG_bom_digikey.csv, MB_bom_digikey.csv]
